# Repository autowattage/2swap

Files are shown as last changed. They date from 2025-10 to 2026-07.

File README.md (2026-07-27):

# 2swap
this is the source files of 2swap, a DIY tv head.

the name 2swap comes from a forth command (where ABCD in the stack translates to CDAB).

watch the video!

Project made for hack club's alleyway program. He first debuted at hackaday supercon 9 and has additionally visited Open sauce 2026!

## specs
twoswap's frame is a cardboard construction ([dimensions](./tvhead/CONCEPT.png)). inside contains a bike helmet, a [laptop screen](https://www.ebay.com/itm/352771352699) + LVDS -> HDMI board, and a raspberry pi zero 2 w. attached is a USB hub with a USB microphone and mini bluetooth keyboard.

said pi zero 2w has dietpi installed, and pygame software runs the display.

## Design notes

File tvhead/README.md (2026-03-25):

# 2swap's head

2swap runs on a raspberry pi 5 and uses pygame to display its graphics.

2swap's frame was planned to be made with 3d print, but is now being made with cardboard.

## 2swap's software
Notes before running:
- you will have to manually adjust audio levels in mouth.py
- you will have to manually set the amount of audio channels in your USB device in mouth.py (twoswap uses a USB microphone, which has 1 in-channel)

F to toggle fullscreen

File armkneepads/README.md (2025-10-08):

# Elbow/Kneepads
light-up LED circuits inside hand-sewn elbow pads and kneepads!

[blue LED schematic](https://ledcalculator.net/#p=6&v=3.5&c=10&n=4&o=w)
[yellow LED schematic](https://ledcalculator.net/#p=6&v=2.4&c=10&n=4&o=w)

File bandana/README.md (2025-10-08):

# Bandana
twoswap's bandana with a keychain containing a RPI pico and mini oled screen.

## Make your own bandana!
1. Get your pieces of fabric.
	- 22x22" square of blue fabric
	- 22x1.5" rectangle of yellow fabric (thin stripe)
	- 22x3" rectange of yellow fabric (thick stripe)
2. On the blue fabric, draw 0.5" margins with a air-fade marker.
3. On both pieces of yellow fabric, draw 0.5" margins on the longest side.
4. Sew the stripes onto the blue fabric.
5. Cut a clean 0.5" radius hole in a corner, using the gap between the stripes as the origin.
6. Insert a 3d printed (link soon) grommet into the hole.
7. YOU DID IT!

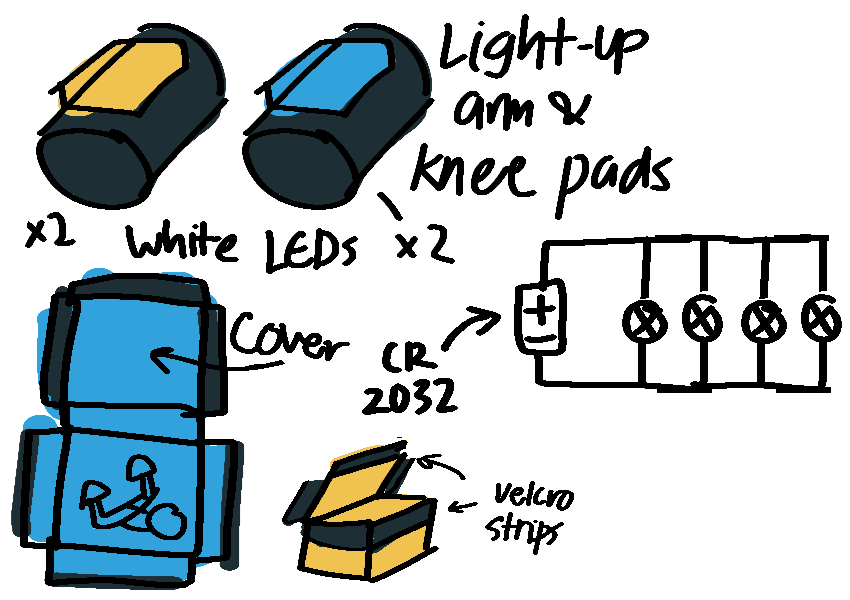
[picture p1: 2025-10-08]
armkneepads/CONCEPT.png

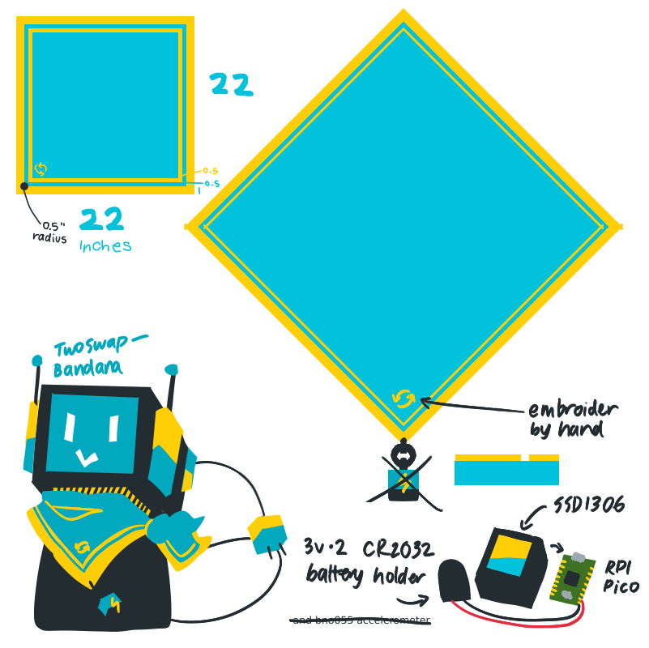
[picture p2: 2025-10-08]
bandana/CONCEPT.png

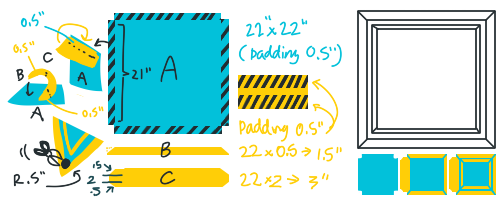
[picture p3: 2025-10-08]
bandana/CONCEPT-1.png

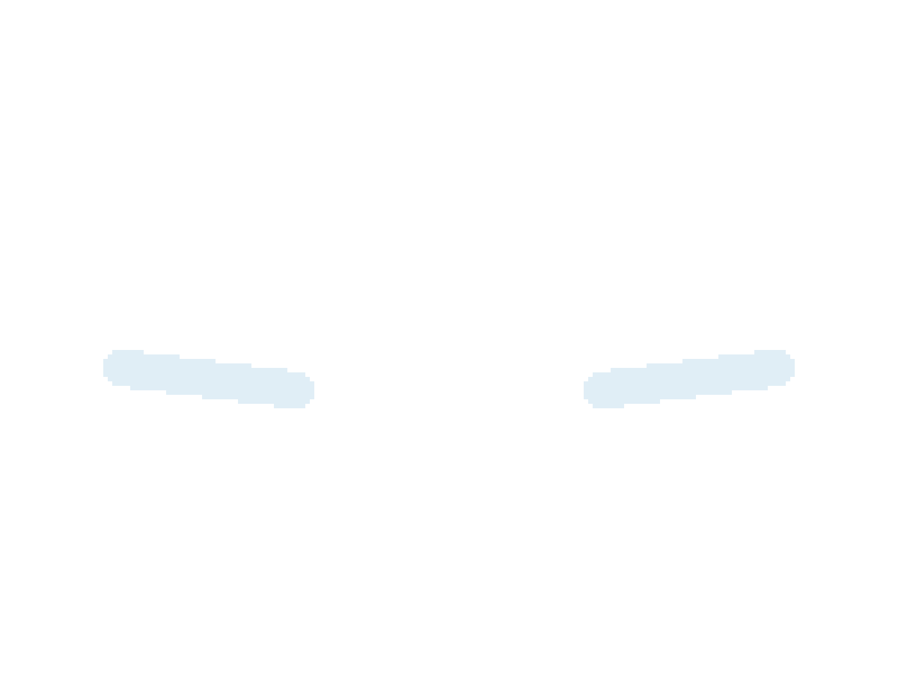
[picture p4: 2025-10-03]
tvhead/software/images/eyes/blink3.png

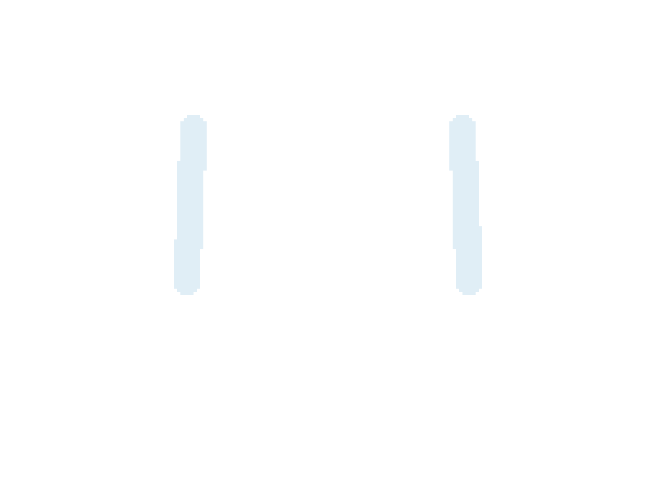
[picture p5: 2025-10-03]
tvhead/software/images/eyes/doubleblink1.png

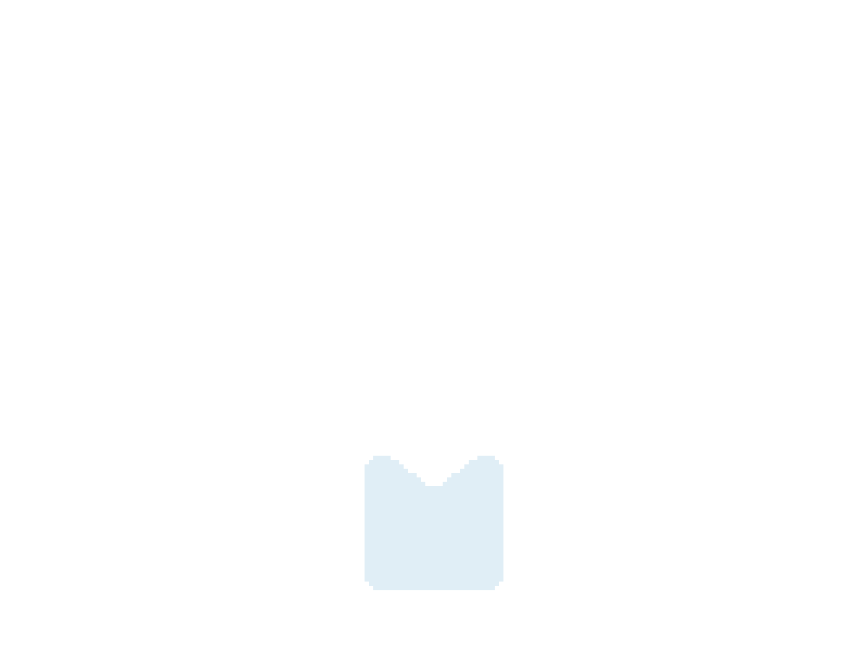
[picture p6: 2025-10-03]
tvhead/software/images/mouth/talk4.png

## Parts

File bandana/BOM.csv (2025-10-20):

Item | Price | Quantity | Notes | Link
CR2032 battery holder (2x3v) | $3.28 | 1.00 | powers the circuit | https://mou.sr/3JIAE64
blue fabric | $5.00 | 0.64 | Measured in yards. The average price of fabric is $5/yd, but prices vary. Purchasing at 23" tall piece of fabric to accomodate for fraying. 23"/1yd*($5/1yd) = 0.638*5 = $3.19 | N/A -- Purchasing at hobby lobby
yellow fabric | $5.00 | 0.17 | Measured in yards. The average price of fabric is $5/yd, but prices vary. Purchasing at 6" tall piece of fabric to accomodate for fraying. 23"/1yd*($5/1yd) = 0.166*5 = $0.83 | N/A -- Purchasing at hobby lobby
CR2032 batteries | $0.33 | 40.00 | powering both the kneepads and bandana.. This is a lot of batteries, and I don't know how long these batteries will last for each use. its ok i think,,, | https://mou.sr/4388VFd
Total | $17.31 | (taxes not included)

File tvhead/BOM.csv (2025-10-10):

Item | Price | Quantity | Notes | Link
12v/5v power bank | $31.99 | 1.00 | To power the monitor and RPI 0 2w | https://www.amazon.com/TalentCell-Rechargeable-12000mAh-Multi-led-indicator/dp/B00ME3ZH7C
Bicycle helmet | $13.06 | 1.00 | So I can actually put the TV Head on. -- previous bike helmet I bought was out of stock. buying another one (sorry alex) | https://www.amazon.com/Wipeout-Erase-Skate-Scooter-Helmet/dp/B00BIVLRMK
Total | $45.05 | (taxes not included)

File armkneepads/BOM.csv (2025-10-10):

Item | Price | Quantity | Notes | Link
CR2032 battery holder (2x3v) | $3.28 | 4.00 | powers the circuit | https://mou.sr/3JIAE64
Blue LEDS | $0.12 | 8.00 | x4 for each LED | https://mou.sr/4mY8Snm
270 ohm resistors | $0.10 | 8.00 | x4 for the blue LEDS, https://ledcalculator.net/#p=6&v=3.5&c=10&n=4&o=w | https://mou.sr/4mSkE2p
120 ohm resistors | $0.10 | 4.00 | x2 for the yellow LEDS https://ledcalculator.net/#p=6&v=2.4&c=10&n=4&o=w | https://mou.sr/4nIfFT7
Total | $15.28 | (taxes not included)

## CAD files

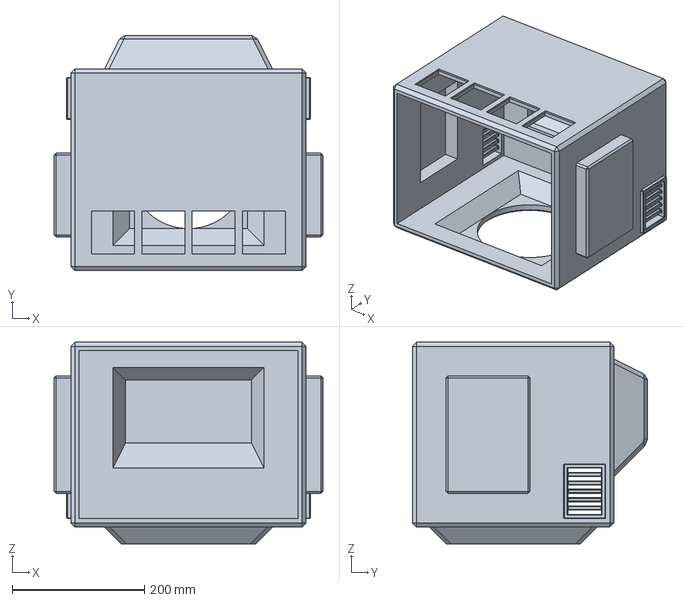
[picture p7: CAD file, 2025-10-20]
tvhead/hardware/3d_model/2swap.FCStd
406.4 x 355.6 x 304.8 mm

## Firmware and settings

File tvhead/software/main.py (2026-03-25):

import pygame
import random
import numpy as np
import eyes, mouth #, tilt #, buttons

running = True
fullscreen = True

# initalize pygame (lol)
pygame.init()
screen = pygame.display.set_mode((1440, 1050), pygame.FULLSCREEN)
clock = pygame.time.Clock()

width, height = screen.get_width(), screen.get_height()
stripe_move = 0 #internal counter variable for screen
offsetca = random.sample(range(-3,3),6) #offset range for chromatic aberration

# blinking interval
face_event = pygame.USEREVENT+1
pygame.time.set_timer(face_event, 1000)

# Colors!
yellow = (255, 206, 7)
light_blue = (2, 168, 190)
dark_blue = (2, 135, 172)
white = (224, 238, 246)

# draw background stripes
def draw_bgstripes(bgcolor, stripecolor):
    screen.fill(bgcolor)
    for i in range(-2,6,2):
        pygame.draw.rect(screen, stripecolor, pygame.Rect(0, stripe_move+i*height/5, width, height/5))

# apply chromatic abberation
def apply_ca(offset, flicker_offset):
    arrayca = pygame.surfarray.array3d(screen) #split into RGB
    for i in range(0,6):
        arrayca[:,:,i%3] = np.roll(arrayca[:,:,i%3], offset[i], axis=1-i//3)
    arrayca[:,:,:] += random.randint(0,flicker_offset) # screen flicker
    pygame.surfarray.blit_array(screen, arrayca)

while running:
    dt = clock.tick(500) # many fps..
    #print(clock.get_fps())
    
    for event in pygame.event.get():
        if event.type == pygame.QUIT:
            running = False
        #elif (not tilt.expression()) and (event.type == face_event): # Tilt sensor broken
        elif (event.type == face_event):
            eyes.blink()
            pygame.time.set_timer(face_event, random.randint(1500,4000)) # 2500 6000
        elif (event.type == pygame.KEYDOWN):
            if (event.key == pygame.K_f):
                fullscreen = not fullscreen
                if fullscreen:
                    screen = pygame.display.set_mode((0, 0), pygame.FULLSCREEN)
                else:
                    screen = pygame.display.set_mode((1200, 850))
    draw_bgstripes(light_blue, dark_blue) #that cool striped background

    #buttons.update_face(screen)
    #if not buttons.active():
    #tilt.update_face(screen)
    #if tilt.expression()==None:
    mouth.update_face(screen)
    eyes.update_face(screen, dt)

    # load into screen
    #apply_ca(offsetca, 5) #chromatic aberration -- use for lower fps
    pygame.display.flip()

    # update tick variables
    stripe_move = stripe_move+0.02*dt if stripe_move<height/2.5 else 0
    

pygame.quit()

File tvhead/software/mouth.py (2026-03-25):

import sounddevice as sd
from collections import deque
import threading
import numpy
import pygame
import os

mouths = [
    pygame.image.load(os.path.join("images", "mouth", "idle.png")),
    pygame.image.load(os.path.join("images", "mouth", "talk1.png")),
    pygame.image.load(os.path.join("images", "mouth", "talk2.png")),
    pygame.image.load(os.path.join("images", "mouth", "talk3.png")),
    pygame.image.load(os.path.join("images", "mouth", "talk4.png"))
]


curr_mouth = mouths[0]
moving_avg = deque(maxlen=8)

def update_face(screen):
    global curr_mouth, mouths
    #print(curr_mouth)
    screen.blit(curr_mouth, (0,0)) #-500 bc my screen too small lol
    
def get_volume(indata, frames, time, status):
    global mouths, curr_mouth, screen
    #print(sd.query_devices())
    volume = int(numpy.linalg.norm(indata)*10)
    #print(volume)
    moving_avg.append(volume)
    volume = int(sum(moving_avg)*5/ len(moving_avg))
    print(volume*"|")
    if volume>35:
    	curr_mouth = mouths[4]
    elif volume>25:
    	curr_mouth = mouths[3]
    elif volume>15:
    	curr_mouth = mouths[2]
    elif volume>5:
    	curr_mouth = mouths[1]
    else:
    	curr_mouth = mouths[0]

def start_audio_stream():  	
    with sd.InputStream(channels=1, callback=get_volume):
        sd.sleep(1000000)

# thread for audio because it cant run same time as pygame...
audio_thread = threading.Thread(target=start_audio_stream)
audio_thread.start()

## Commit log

2025-10-01 BOM, sketches, and other small things..
    [BOM.csv]
2025-10-08 removed controller folder, added elbow\/kneepad and bandana folder
    [2swap.FCStd, BOM.csv]
2025-10-10 update 2swap model
    [2swap.FCStd]
2025-10-10 update bom
    [BOM.csv]
2025-10-10 fixed tvhead and bandana bom
    [BOM.csv]
2025-10-20 3dmodel updates, add face expressions to tvhead
    [2swap.FCStd, BOM.csv]
2025-10-22 for now, disable chromatic abberation for performance.. and boilerplate sensor code
2025-10-27 boilerplate button code and readme tweak
2025-10-29 broken code on the pi..
    [main.py, mouth.py]
2025-10-29 Bno055 i2c test 1
2025-10-30 button test boilerplate code
2026-01-29 display resolution fix, disable sensor input bc twoswaps rpi5 broke and i dont have a microUSB adaptor for the microphone LOL
    [eyes.py, main.py, mouth.py]
2026-03-25 new commits on the twoswap device, fixed audio levels.
    [mouth.py]
